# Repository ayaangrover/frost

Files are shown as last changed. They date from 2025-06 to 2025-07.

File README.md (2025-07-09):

github

# Frost
### An OSHWA-certified 75% bluetooth hotswappable mechanical keyboard with over 3 months of battery.
### About:
Frost uses a nice!nano v2, and a 110mah battery that will last up to 5 months. The nice!nano gives it bluetooth, and my configuration gets all the parts for under $150(other than the case). Also uses Cherry clip-in stabilizers and kailh hotswap sockets and M2(4mm) heatset inserts and screws to fasten the pcb to the case. Frost is OSHWA certified with UID US002745.

### BOM:

| Item | Cost |
|---|---|
| MCU (nice!nano v2) | $25.00 |
| Battery (110mAh) | $3.00  |
| Switches | $19.30 |
| PCB | $58.23 |
| Stabilizers | $9.50  |
| Hotswap Sockets | $0.99  |
| Fasteners | $3.66  |
| Diodes | $1.99  |
| Keycaps | $16.99 |
| Foam | $9.99  |
| **Total** | **$148.65** |

#### Links:

- MCU: https://bit.ly/43MxEzh (Free shipping, $25+)
- Battery: https://bit.ly/4mHn5pD (Free shipping with mcu)
- Switches: https://bit.ly/4dSzwen - MMD Princess Tactile 48g x90, under $20
- Stabilizers: https://bit.ly/3FuRC9E - KBD Fans, Cherry Clip in PCB Mount, pre lubed
- Hotswap Sockets: https://bit.ly/4dIZlgY
- Fasteners(3.2mm diameter on the heatset inserts, m2 heatsets and screws): https://bit.ly/43L1Xq4 and https://bit.ly/3Zae3aP
- Diodes: random aliexpress brand, doesnt matter which one since they're all very cheap
- Keycaps: Any
- Foam: [https://www.amazon.com/HONKID-Keyboard-Foam-Mechanical-3mm/dp/B0CPPNF7NR?sr=8-4](https://www.amazon.com/HONKID-Keyboard-Foam-Mechanical-3mm/dp/B0CPPN2J8F?sr=8-4)

### Case:

Made with Fusion 360. Available at /case. Also includes the plate.

### Firmware:

The firmware was made with ZMK, since the MCU for the keyboard(a nice!nano v2) was built specifically for use with ZMK. ZMK has inbuilt bluetooth support as well as support for displaying the batery capacity on the paired device. Firmware is at /firmware.

### Renders: 

Schematic
CleanShot 2025-06-06 at 13 54 51
CleanShot 2025-06-05 at 14 30 57
CleanShot 2025-07-08 at 17 00 20
CleanShot 2025-07-08 at 16 49 49
CleanShot 2025-07-08 at 16 48 03

### Licensing:

oshw_facts

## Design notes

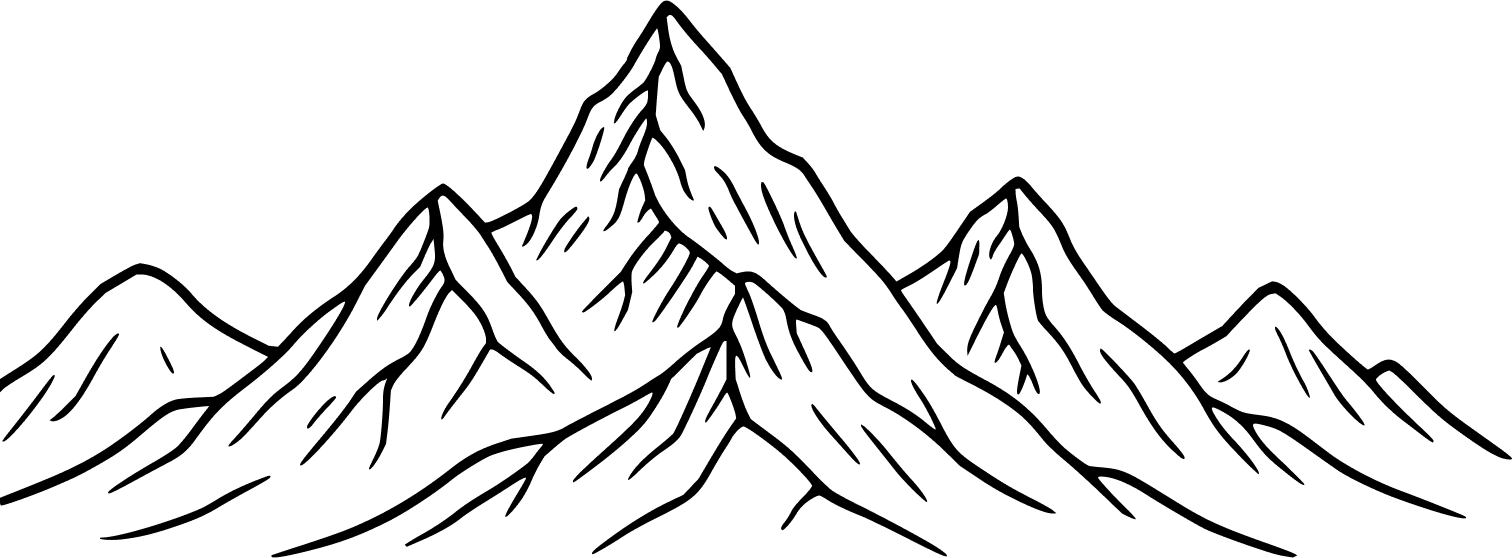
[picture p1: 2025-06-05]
assets/Vector.png

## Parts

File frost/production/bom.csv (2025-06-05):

Designator | Footprint | Quantity | Value | LCSC Part #
D1, D10, D11, D12, D13, D14, D15, D16, D17, D18, D19, D2, D20, D21, D22, D23, D24, D25, D26, D27, D28, D29, D3, D30, D31, D32, D33, D34, D35, D36, D37, D38, D39, D4, D40, D41, D42, D43, D44, D45, D46, D47, D48, D49, D5, D50, D51, D52, D53, D54, D55, D56, D57, D58, D59, D6, D60, D61, D62, D63, D64, D65, D66, D67, D68, D69, D7, D70, D71, D72, D73, D74, D75, D76, D77, D78, D79, D8, D80, D81, D9 | Diode_DO-35 | 81 | Diode
S1, S10, S11, S12, S13, S14, S15, S16, S17, S18, S19, S2, S20, S21, S22, S23, S24, S25, S26, S27, S28, S3, S31, S32, S33, S34, S35, S36, S37, S38, S39, S4, S40, S41, S42, S45, S46, S47, S48, S49, S5, S50, S51, S52, S53, S54, S55, S57, S59, S6, S60, S61, S62, S63, S64, S65, S66, S67, S68, S7, S70, S71, S76, S77, S78, S79, S8, S80, S81, S9 | Hotswap_MX_1.00u | 70 | Keyswitch
S29 | Hotswap_MX_2.00u | 1 | Keyswitch
S30, S43 | Hotswap_MX_1.50u | 2 | Keyswitch
S44, S69 | Hotswap_MX_1.75u | 2 | Keyswitch
S56, S58 | Hotswap_MX_2.25u | 2 | Keyswitch
S72, S73, S74 | Hotswap_MX_1.25u | 3 | Keyswitch
S75 | Hotswap_MX_6.25u | 1 | Keyswitch
U1 | Nice_Nano_V2 | 1 | Nice_Nano_V2

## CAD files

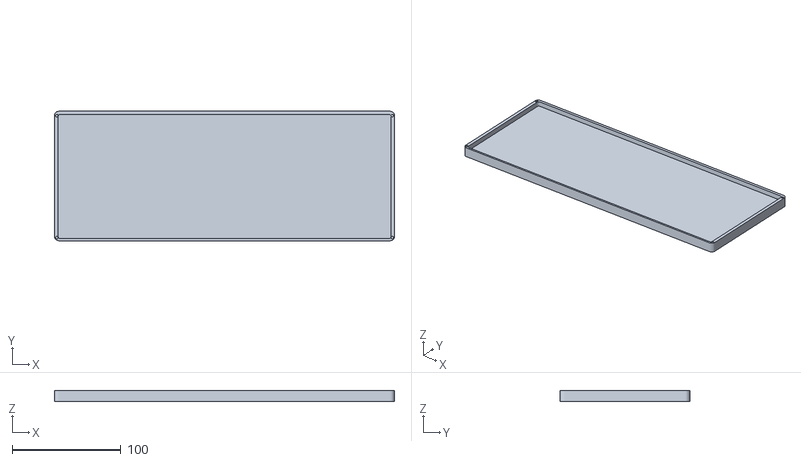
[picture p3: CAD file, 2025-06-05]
assets/case2 v10.stl
312.3 x 119.1 x 10.0

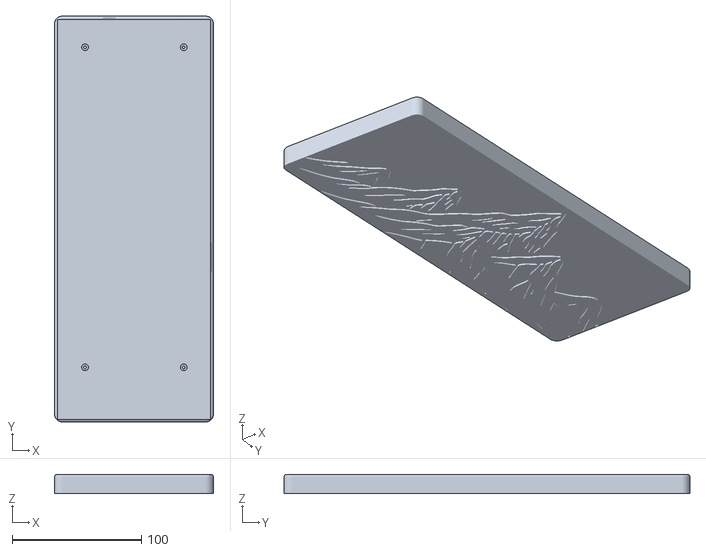
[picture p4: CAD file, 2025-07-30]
case/case.stl
123.0 x 314.0 x 15.0

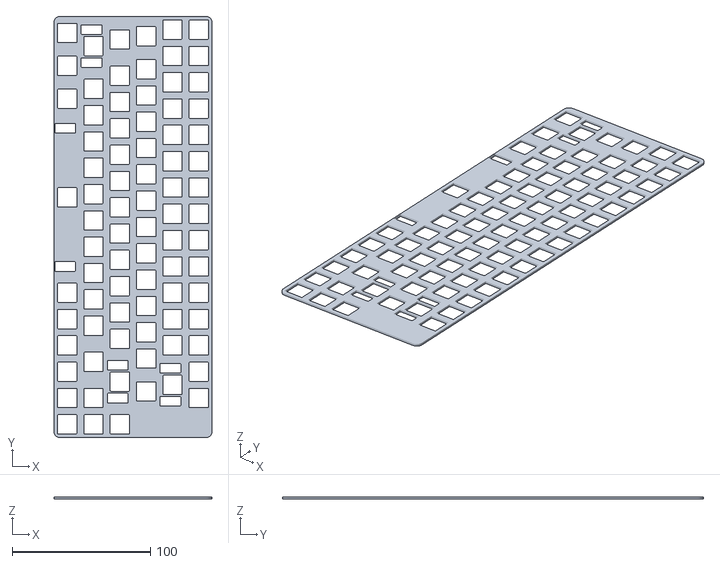
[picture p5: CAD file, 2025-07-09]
case/plate.stl
114.3 x 304.8 x 1.60

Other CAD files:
case/frost v5.stl

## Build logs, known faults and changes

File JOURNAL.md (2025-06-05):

# Frost: Journal
Total time: ~34 hrs

### May 31: 5 hrs 43 min
During this session, I did a bunch of research, made my schematic, and began my pcb!

#### My Research:
1. Switches - MMD Princess Tactile, 48g. Thocky but tactile, budget friendly
2. MCU - Nice!Nano v2 for easy bluetooth and battery support. Has a lot of cheap knockoff versions on aliexpress
3. Keyboard Size - 75%, 81 keys - nice!nano only has 18 exposed pins so i removed 3 switches and put the mcu there. Less space needed as well since i can tuck the tiny battery under the mcu!
4. Case and fastening - screw the pcb to the case. simple and inexpensive
5. Plate - Nope, direct pcb mount. Looks cool, and i can do it all in white(matches my sister's desk color scheme)
6. Stabilizers - Cherry Stabs (Clip in, PCB Mount, from KBDFans)
7. Battery - 110mah, aliexpress - fits under MCU
8. Hotswap Sockets - kailh hotswap sockets from aliexpress
9. Diodes - THT, easier to solder
10. Keycaps - cheap $17 set from amazon

| Item | Cost |
|---|---|
| MCU (nice!nano v2) | $25.00 |
| Battery (110mAh) | $3.00  |
| Switches | $19.30 |
| PCB | $59.00 |
| Stabilizers | $9.50  |
| Hotswap Sockets | $0.99  |
| Fasteners | $3.48  |
| Diodes | $2.34  |
| Keycaps | $16.99 |
| **Total** | **$139.60** |

#### Links:

MCU: https://bit.ly/43MxEzh (Free shipping, $25+)
Battery: https://bit.ly/4mHn5pD (Free shipping with mcu)
Switches: https://bit.ly/4dSzwen
Stabilizers: https://bit.ly/3FuRC9E
Hotswap Sockets: https://bit.ly/4dIZlgY
Fasteners(3.2mm diameter on the heatset inserts, m2 heatsets and screws): https://bit.ly/43L1Xq4 and https://bit.ly/3Zae3aP
Diodes: random aliexpress brand, doesnt matter which one
Keycaps: Any

Since the n!n has only 18 exposed pins, I'm going to do a 9x9 matrix in the schematic and drop 3 switches from a regular 75% layout and put my MCU and logo/name there.

Update - I just finished for today. Schematic is done, and pcb started but barely. Had to go back because I forgot the diodes though.

Here's what the schematic looks like(after I added the diodes):

Schematic

### Jun 1: 9 hrs 38 min
Did all the organizing, layouts, and wiring today! PCB is now fully finished, and it looks good. I added a snowflake icon since it's called Frost. It's looking amazing! Took a long time and looks a bit messy though because the schematic and pcb wiring diagram differ a bit - 9x9 vs 6x15. Also added stab holes and case attatchment holes. I used over 200 vias and over 1100 track segments!

Here are some images of the process and final renders:

PCB
PCB
PCB 3D View
PCB JLCPCB Render

### Jun 2: 7 hrs 19 min

Made my ZMK code but stuck on an issue in GH Actions where it says it can't find my shield. Made a new repo for my zmk code though - frost-module as per the zmk docs.

Took a LONG time to learn ZMK. There are very few tutorials and explanations online, and the docs are somewhat unclear and they contradict themselves a bit too.

### Jun 3: 2 hrs 4 min

Worked on that error. Asked online but the people's suggestions didn't work very well. Also asked Gemini but it hallucinated a LOT.

### Jun 4: 8 hrs 9 min

Someone else responded to my discord post in scottokeebs server, and pointed out an error in my module.yml where I put ```board_root: ..``` instead of ```board_root: .```

Then I worked on other errors, since there were lots of issues with my overlay and keymap.

Eventually, and with a bit of help from Claude Sonnet 4, I managed to produce a working copy of the firmware! It's available in /firmware - both the .uf2 and the full uncompiled version.

Also started the case in Fusion 360 - it's going to be a very simple design since I want the pcb fully exposed. That way the signal strength from the nice!nano isn't impacted at all.

### Jun 4: 35 min - in the call!

Finished the case! It's pretty simple - here's an image:

Case

Also applied for the 1 point bonus!

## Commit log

2025-06-05 add main stuff
    [bom.csv, designators.csv, frost.kicad_sch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]
2025-06-05 add case(zoom call!)
    [Case v14.stl]
2025-06-05 add updates
    [case2 v10.stl, case2 v11.stl, designators.csv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]
2025-06-06 Rename Neat Jaban (1).stl to case.stl
    [case.stl]
2025-06-06 Rename case.stl to case2 v12
2025-06-06 Rename case2 v11.stl to case
2025-06-06 Rename case2 v12 to (fancier)case
2025-06-07 fix case+plate v2
    [case_plate_2.stl]
2025-07-09 Rename Frantic Tumelo-Snaget (3).stl to plate.stl
    [plate.stl]
2025-07-09 Rename frost v5.stl to case.stl
    [case.stl]
